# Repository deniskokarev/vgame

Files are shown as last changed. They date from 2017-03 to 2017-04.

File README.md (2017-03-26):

STM32F3 and Nokia LCD mini-game console

* doc - various datasheets
* hard - DipTrace schematics and PCB design
* soft - CubeMX/HAL-based project compilable with GNU toolkit

Standard Makefile compilation on Mac and Linux. Requires:
* gcc-arm-none-eabi - ARM GCC compiler: https://launchpad.net/gcc-arm-embedded
* STM32Cube_FW_F3_V1.7.0 - HAL library: http://www.st.com/en/embedded-software/stm32cubef3.html - click on "Get Software"
* stlink tools (st-flash/st-util) - to flash/debug firmware with STLink programmer: https://github.com/texane/stlink
* STLink programmer itself: http://www.st.com/en/development-tools/st-link-v2.html
* if you plan to change hardware you will need STM32CubeMX tool: http://www.st.com/en/development-tools/stm32cubemx.html - click on "Get Software" 

```
make && make flash
```
then to debug

```
xterm -e st-util &		# spawn st-util on different console
make debug
```

The current software is the Game of Reversy (Otello)

The board is double-sided suitable for DIY and fits the LCD screen component "natively"

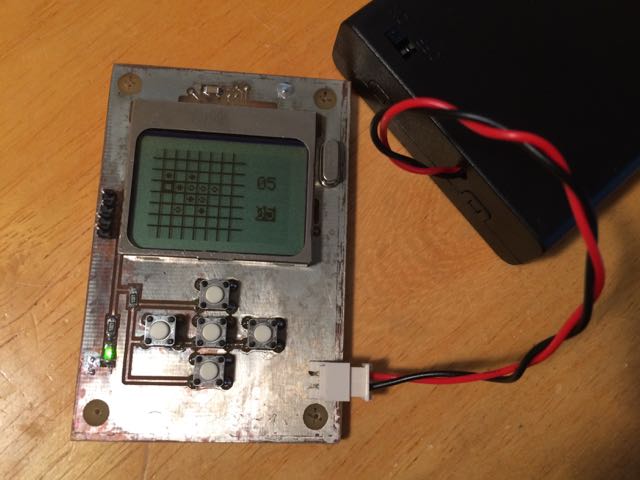
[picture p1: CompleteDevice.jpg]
Complete Device


TODO:
- Write more games

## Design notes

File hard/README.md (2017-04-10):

# DipTrace schematics and PCB design

* vgame.dch - schematics
* vgame.dip - PCB

Yeah, I know, the capacitors polarity is inverted everywhere on the schematic. But at least it's consistently inverted and for small ceramic caps as these it doesn't matter anyway ;-)

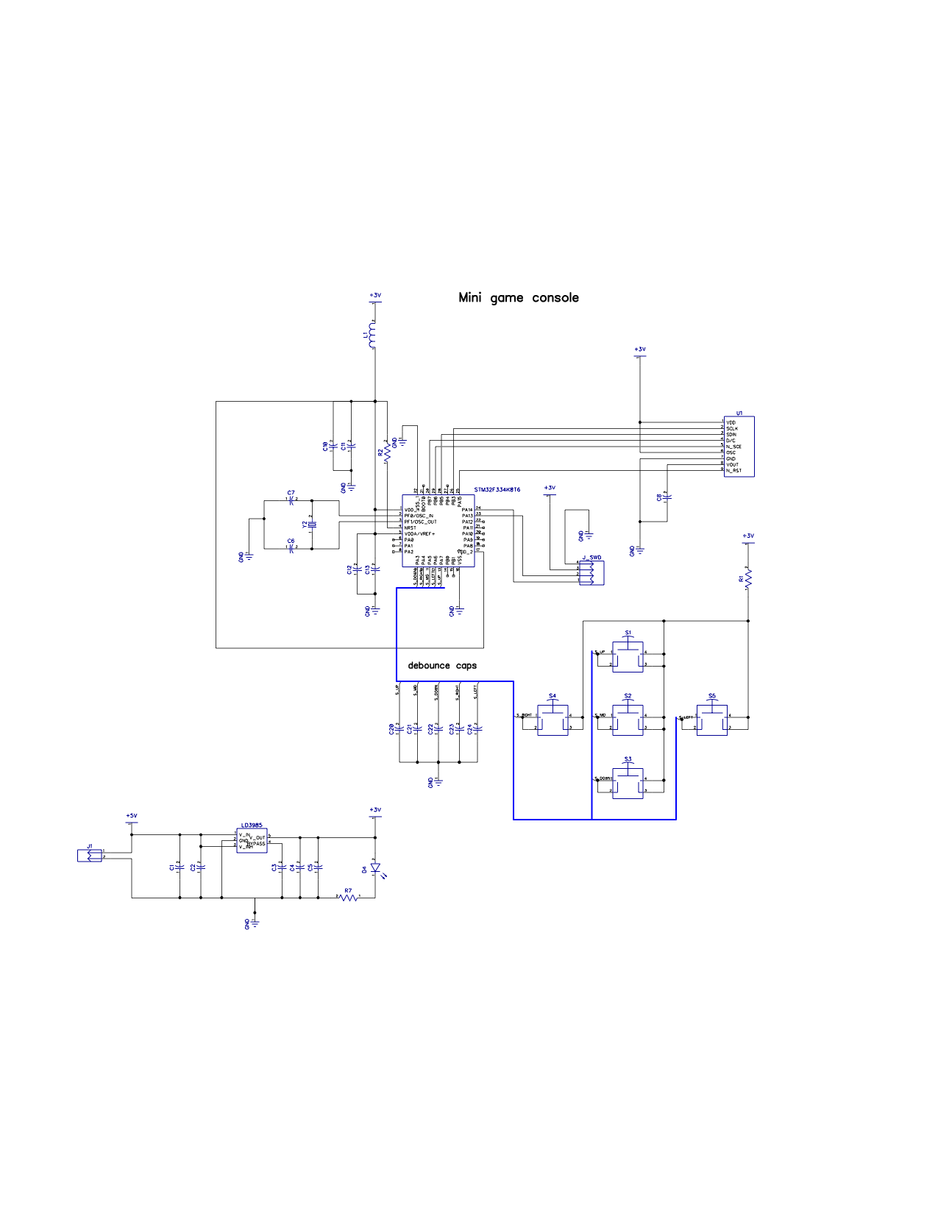
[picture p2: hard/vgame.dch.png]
Schematics


TODO:
* USB power supply
* Start using microcontroller with USB host interface
* LiPo rechargable battery
* Charger for the battery
* Speaker or buzzer for sound effects
* Power on/off for screen and sound system
* Measure the power supply in the deep sleep mode and if consumption permits avoid using the main power switch
* May be add one more "menu" button

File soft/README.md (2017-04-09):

# Game of Reversy formware for our mini-console

Player vs computer mode.

* soft.ioc - CubeMX hardware project file: our hardware-specific stuff
* Src, Inc and TrueSTUDIO - HAL-based source code redndered by CubeMX
(Except 2 lines in Src/main.c where our code begins)
* cube3.mk - generic makefile for Cube F3 HAL library-based projects 
* Makefile - our project makefile
* STM32F334K8_FLASH.ld - linker script rendered by CubeMX for our chip

There are two external modules used:
* git submodule add https://github.com/deniskokarev/reversy
* git submodule add https://github.com/adafruit/Adafruit-GFX-Library

Also Adafruit-PCD8544-Nokia-5110-LCD-library library was ported to STM32 with HAL layer and DMA mode.

program.cpp has higher user-level API to work with our hardware

reversy_program.cpp is the actual game code

cxx.c necessary stubs to make c++ happy

The code is commented in doxygen fashion, with `make doc` rule producing doxy directory with documentation

TODO:
- rename sleep() methods
- observe infinite refresh rate
- add color and difficulty selection to the startWindow

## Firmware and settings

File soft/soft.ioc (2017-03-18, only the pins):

Mcu.UserName=STM32F334K8Tx
PA13.Signal=SYS_JTMS-SWDIO
PA14.Signal=SYS_JTCK-SWCLK
PA15.Signal=GPIO_Output
PA3.Signal=GPXTI3
PA4.Signal=GPXTI4
PA5.Signal=GPXTI5
PA6.Signal=GPXTI6
PA7.Signal=GPXTI7
PB3.Signal=SPI1_SCK
PB4.Signal=SPI1_MISO
PB5.Signal=SPI1_MOSI
PB6.Signal=GPIO_Output
PB7.Signal=GPIO_Output

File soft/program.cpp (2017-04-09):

/**
 * @file
 * @brief User-level API to progrm our mini-console
 * @author Denis Kokarev
 */

#include "program.h"
#include "gpio.h"
#include "spi.h"	// has hspi1
#include "rtc.h"

/*
 * all of these must match the CubeMX initialized PINs
 * the SPI handle is expected to be named hspi1
 */
const static STM_HAL_Pin dc {GPIOB, GPIO_PIN_7};		///< our data/command hardware pin as per schematics
const static STM_HAL_Pin cs {GPIOB, GPIO_PIN_6};		///< our SPI chip select pin as per schematics
const static STM_HAL_Pin rst {GPIOA, GPIO_PIN_15};		///< our reset screen pin as per schematics

/*** Events Queue *************************************/

/**
 * @brief Our system event queue is a ring buffer
 */
class RingbufQueue: public EventQueue {
protected:
	Event *q;	///< memory location for the ringbuf
	int sz;		///< size of the buffer
	int h;		///< head of the queue
	int t;		///< tail of the queue
public:
	/**
	 * @brief initialize the RingBuffer on the predefined buffer
	 * @param _q - event buffer location
	 * @param _sz - sz its size in number of events
	 */
	RingbufQueue(Event *_q, int _sz):q(_q),sz(_sz),h(0),t(0) {
	}
	/**
	 * @brief simple implementation
	 */
	virtual Event get() override {
		if (t != h) {
			Event rc = q[h];
			h = (h+1) % sz;
			return rc;
		} else {
			return Event::EV_NONE;
		}
	}
	/**
	 * @brief simple implementation
	 */
	virtual void put(Event e) override {
		int nt = (t+1) % sz;
		if (nt != h) {
			q[t] = e;
			t = nt;
		} // otherwise just ignore
	}
};

/* our events queue */
constexpr int EQ_SZ = 16;
static Event q[EQ_SZ];
static RingbufQueue rbevents(q, EQ_SZ);

/**
 * @brief our global events queue is an instance of RingbufQueue()
 */
EventQueue *events = &rbevents;

/*** Program ******************************************/


/**
 * @brief all Programs share the knowledge which one of them is the main program
 */
static Program *main_program;

void Program::setMainProgram(Program *p) {
	main_program = p;
}

/**
 * @brief any derived program must invoke the parent constructor
 *
 * Merely declare your Program object to register it as main program
 * If you'll be declaring multiple programs the last constructed one
 * will become main_program
 * In that case, it would be a good idea to incapsulate all programs
 * into a single global object to specify which one to be created last
 */
Program::Program():display(hspi1, dc, cs, rst),refresh(1) {
	setMainProgram(this);
}

/** typical program initialization */
void Program::init() {
	display.begin();
}

/* need this fn defined in main.c, which is not exported */
extern "C" void SystemClock_Config(void);

/**
 * enter STOPSLEEP mode - best energy efficiency slower wakeup
 * to be awoken either by a key
 * or on timeout
 */
void Program::stopSleep(int sec) {
	/* Disable Wake-up timer */
	HAL_RTCEx_DeactivateWakeUpTimer(&hrtc);
	HAL_RTCEx_SetWakeUpTimer_IT(&hrtc, 2500*sec, RTC_WAKEUPCLOCK_RTCCLK_DIV16);
	/* Enter Stop Mode */
	HAL_PWR_EnterSTOPMode(PWR_LOWPOWERREGULATOR_ON, PWR_STOPENTRY_WFI);

	/* Configures system clock after wake-up from STOP: enable HSI and PLL with HSI as source*/
	SystemClock_Config();
	/* Disable Wake-up timer */
	if (HAL_RTCEx_DeactivateWakeUpTimer(&hrtc) != HAL_OK) {
		/* Initialization Error */
		Error_Handler(); 
	}
}

/**
 * enter SLEEP mode - reasonable enery efficiency with fast wakeup
 * to be awoken either by a key
 * or on timeout
 */
void Program::sleepSleep(int sec) {
	/* Disable Wake-up timer */
	HAL_RTCEx_DeactivateWakeUpTimer(&hrtc);
	HAL_RTCEx_SetWakeUpTimer_IT(&hrtc, 2500*sec, RTC_WAKEUPCLOCK_RTCCLK_DIV16);

	/*Suspend Tick increment to prevent wakeup by Systick interrupt. 
	  Otherwise the Systick interrupt will wake up the device within 1ms (HAL time base)*/
	HAL_SuspendTick();

	/* Request to enter SLEEP mode */
	HAL_PWR_EnterSLEEPMode(PWR_MAINREGULATOR_ON, PWR_SLEEPENTRY_WFI);

	/* Resume Tick interrupt if disabled prior to sleep mode entry*/
	HAL_ResumeTick();

	/* Disable Wake-up timer */
	if (HAL_RTCEx_DeactivateWakeUpTimer(&hrtc) != HAL_OK) {
		/* Initialization Error */
		Error_Handler(); 
	}
}

/**
 * @brief our typical execution loop
 */
void Program::execute() {
	init();

	while (true) {
		Event event = events->get();
		switch(event) {
		case Event::EV_NONE:
			sleepSleep(refresh);
			break;
		default:
			Event he = handleEvent(event);
			if (he == Event::EV_CLOSE)
				return;	// for example if main_program changed
		}
	}
}

/** when need to change sleep cycle */
void Program::setRefresh(int r) {
	refresh = r;
}

/*** WProgram *****************************************/

/**
 * one window can pass the control to another windows this way
 */
void WProgram::setMainWindow(Window *w) {
	mainWindow = w;
	mainWindow->draw();
}

/*! WProgram simply delegates its main window to handle events */
Event WProgram::handleEvent(Event event) {
	return mainWindow->handleEvent(event);
}

/*** Hooks to HAL C code ******************************/

extern "C" {

	/**
	 * @brief Buttons IRQ handler
	 *
	 * Convert interrupst into application level events
	 * The name of the function must exactly match to what HAL library expects
	 */
	void HAL_GPIO_EXTI_Callback(uint16_t GPIO_Pin) {
		switch (GPIO_Pin) {
		case GPIO_PIN_3:
			events->put(Event::EV_KEY_DOWN);
			break;
		case GPIO_PIN_4:
			events->put(Event::EV_KEY_RIGHT);
			break;
		case GPIO_PIN_5:
			events->put(Event::EV_KEY_ENTER);
			break;
		case GPIO_PIN_6:
			events->put(Event::EV_KEY_LEFT);
			break;
		case GPIO_PIN_7:
			events->put(Event::EV_KEY_UP);
			break;
		}
	}

	/**
	 * @brief RTC wakeup IRQ handler
	 *
	 * Convert interrupst into application level events
	 * The name of the function must exactly match to what HAL library expects
	 */
	void HAL_RTCEx_WakeUpTimerEventCallback(RTC_HandleTypeDef *hrtc) {
		events->put(Event::EV_TIMER);
	}

	/**
	 * @brief Entry point from main.c to all our event handling infrastructure
	 *
	 * Execute the current main program. When it finishes - execute the main program again
	 * This way a program may transfer the focus to another program
	 */
	void exec() {
		while(true)
			main_program->execute();
	}

}

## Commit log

2017-03-12 adding everything
    [Bottom.gbr, Top.gbr]
2017-03-12 doing renames
    [Bottom.gbr, Top.gbr]
2017-03-12 must disconnect BOOT0 from GND
2017-03-14 switching from SparkFun library into Adafruit GFX library start using C++ code
2017-03-15 start using SPI transfer with DMA also increase SPI transmission rate to 4Mbit also ignore rendering box adjustment for simplification
2017-03-15 oops forgot to add dma files
2017-03-15 pushing CPU clock to 72MHz and SPI bus to 4.5Mbit/s
2017-03-18 adding button interrupts and experimental RTC-based sleep mode
2017-03-18 adding RTC interrupt handler
2017-03-18 configuring out button pins as pull-down
2017-03-18 echoing back the button that was pressed
2017-03-19 adding game board
2017-03-19 drawing game board and cursor
2017-03-26 correcting left/right button names and adding png file for schematics
2017-04-02 adding AUTOTEST macro in case if we need to benchmark/test performance
2017-04-08 need to switch to the latest game algorithm
